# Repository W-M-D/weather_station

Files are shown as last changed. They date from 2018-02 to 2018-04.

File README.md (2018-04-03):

# weather_station

The ultimate in nrf52832 based APRS weather stations! 

Just a quick update after finding that you can buy a weather station replacement kit for ~$70 that has a few radios that is already supported by rtl_433 i sat down and did some thinking. What could i do that would be more universal. Like the ultimate Ham hacking kit. After much debate with myself. I have decided to make something much more generic.  But i also wanted to create something that was much more than a simple dev board. I'm keeping the universality down to one radio besides the Bluetooth one. But i am going to add a raspberry pi header for reasons. My goal is to make a device that, with your ham radio, you can create anything you desire within the limits of the community and APRS.

Another update i'm still going to make a version of the board with out the raspberry pi HAT. I'm going to elimiate most of the hardware since i'm planning on reading from external sensors. I'm planning on breaking out the nrf52832 to pin headers to connect the hardware. This will still run off 4 18650s and will still have the solar MPPT circuit.

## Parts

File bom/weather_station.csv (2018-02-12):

Id | Designator | Package | Quantity | Designation | Supplier and ref
1 | M1 | WireConnection_2.00mmDrill | 1 | ANEOMETER |  |  | 0
2 | C9 | C_0402 | 1 | 100pF | 399-1022-1-ND |  | 0
3 | BT1,BT2,BT3,BT4 | Keystone_1042_1x18650 | 4 | 18650Cell | 36-1042P-ND | $2.47 | 9.88 | 9.88
4 | C1,C2,C20 | C_1206 | 3 | 10uF | 490-5525-1-ND | 0.28 | 0.84 | 10.72
5 | C3 | C_0402 | 1 | 4.7uF | 490-5915-1-ND | $0.16 | 0.16 | 10.88
6 | C4,C10,C11,C21,C25 | C_0402 | 5 | 100nF | 587-1227-1-ND | $0.10 | 0.5 | 11.38
7 | C5,C7,C16,C18 | C_0402 | 4 | F_cap | N/A |  | 0 | 11.38
8 | C6,C17 | C_0402 | 2 | Diff_Cap | N/A |  | 0 | 11.38
9 | C8,C23 | C_0402 | 2 | 1uF | 587-1251-1-ND | $0.10 | 0.2 | 11.58
10 | C14,C15 | C_0402 | 2 | 12pF | 490-6197-1-ND | $0.10 | 0.2 | 11.78
11 | D2 | LED_RGB_PLCC-6 | 1 | LTRB GFSF | 475-2899-1-ND | 1.08 | 1.08 | 12.86
12 | DRA1 | DRA818U | 1 | DRA818U | DRA818V | 9.44 | 9.44 | 22.3
13 | L3 | C_0402 | 1 | 3.3nH | 712-1416-1-ND | $0.10 | 0.1 | 22.4
14 | L4 | C_0402_NoSilk | 1 | tuning_inductor |  |  | 0 | 22.4
15 | MK1,MK2,MK3,MK4 | MountingHole_3.5mm_Pad | 4 | Mounting_Hole | N/A | 0 | 0 | 22.4
16 | U1 | SO-8C | 1 | LM1117IMP-3.3 | LM1117IMP-3.3 | 1.14 | 1.14 | 23.54
17 | U2 | TSSOP-16_4.4x5mm_Pitch0.65mm | 1 | ADS1120-PW | 296-39550-5-ND | 7.92 | 7.92 | 31.46
18 | U3 | UQFN-48-1EP_6x6mm_Pitch0.4mm | 1 | nRF52832 | 1490-1055-1-ND | 5.59 | 5.59 | 37.05
19 | Y1 | Crystal_SMD_3225-4pin_3.2x2.5mm | 1 | FL3200037 | FL3200037CT-ND | $0.69 | 0.69 | 37.74
20 | C22 | FV1206-1 | 1 | EMI_Filter_C | LFCN 180+ | $0.01 | 0.01 | 37.75
21 | JP1 | Pin_Header_Straight_1x02_Pitch2.54mm | 1 | Jumper | N/A |  | 0 | 37.75
22 | Q1 | SOT-23 | 1 | Q_NMOS_DGS | SSM3K329RLFCT-ND | 0.54 | 0.54 | 38.29
23 | C24 | C_0402 | 1 | 10nF | 490-1313-1-ND | $0.10 | 0.1 | 38.39
24 | C26,C29,C30 | C_0402 | 3 | C_Small | N/A |  | 0 | 38.39
25 | U5 | LGA-8_3x5mm_Pitch1.25mm | 1 | MPL115A1 | MPL115A1-ND | 5.85 | 5.85 | 44.24
26 | MK5,MK6,MK7,MK8 | Measurement_Point_Square-SMD-Pad_Big | 4 | Mounting_Hole_PAD |  |  | 0 | 44.24
27 | C12,C13 | C_0603 | 2 | tuning_cap |  |  | 0 | 44.24
28 | R1,R6,R10,R13 | R_0603 | 4 | 10MΩ | 311-10MGRCT-ND | 0.1 | 0.4 | 44.64
29 | R4,R5,R11,R12 | R_0603 | 4 | 510Ω | RHM510DCT-ND | $0.10 | 0.4 | 45.04
30 | R7,R8,R9 | R_0603 | 3 | 255Ω | RHM510DCT-ND | $1.10 | 3.3 | 48.34
31 | R16,R21,R30,R31,R32 | R_0603 | 5 | 100kΩ | RR08P100KDCT-ND | $0.11 | 0.55 | 48.89
32 | R17 | R_0603 | 1 | 3.3kΩ | RHM3.3KDCT-ND | 0.1 | 0.1 | 48.99
33 | R18 | R_0603 | 1 | 1.8KΩ | RR08P1.8KDCT-ND | $0.11 | 0.11 | 49.1
34 | U6 | QFN-24-1EP_3x3mm_Pitch0.4mm | 1 | LIS3MDLTR | 497-13892-1-ND | 1.67 | 1.67 | 50.77
35 | J3,J4 | SMA_SMD_Jack_Straight | 1 | Conn_Coaxial | J10154CT-ND | 5.38 | 10.76 | 61.53
36 | R2,R3 | R_0603 | 2 | 1.8kΩ | RR08P1.8KDCT-ND | 0.11 | 0.22 | 61.75
37 | J2 | Pin_Header_Straight_2x10_Pitch2.54mm | 1 | Conn_02x10_Odd_Even |  |  | 0 | 61.75
38 | Y2 | Crystal_SMD_EuroQuartz_EQ161-2pin_3.2x1.5mm | 1 | 32.786khz | 1253-1335-1-ND | 0.66 | 0.66 | 62.41
39 | AE1 | SMA | 1 | ant |  |  | 0 | 62.41
40 | C27,C28,C32,C34,C37,C39 | C_0805 | 6 | 1.0uF | 311-1365-1-ND | 0.11 | 0.66 | 63.07
41 | C31,C33,C38,C41,C42 | C_0805 | 5 | 0.1uF | 399-1170-1-ND | 0.1 | 0.5 | 63.57
42 | C35,C43 | CP_Elec_6.3x7.7 | 2 | 100uF | 493-2105-1-ND | 0.33 | 0.66 | 64.23
43 | C36,C40 | CP_Elec_6.3x7.7 | 2 | 47uF | 493-2176-1-ND | 0.35 | 0.7 | 64.93
44 | D3 | TO-252-2_Rectifier | 1 | MBRD10100CT | 1655-1464-1-ND | 0.45 | 0.45 | 65.38
45 | D4 | D_SOD-523 | 1 | D_Schottky | BZT585B5V1TQ-7DICT-ND | 0.29 | 0.29 | 65.67
46 | J6 | Pin_Header_Straight_1x02_Pitch2.54mm | 1 | SOLAR | 1597-1414-ND | 12.19 | 12.19 | 77.86
47 | L5 | Inductor_Wurth_HCI-1890 | 1 | 3.3uH | 732-2165-1-ND | 2.01 | 2.01 | 79.87
48 | Q2,Q3,Q4,Q5 | TDSON-8-1 | 4 | FDMS8050 | FDMS8050ET30CT-ND | 3.73 | 14.92 | 94.79
49 | R27,R28 | R_2512 | 2 | 0.010Ω | 311-0.1ARCT-ND | 0.57 | 1.14 | 95.93
50 | U4 | QFN-16-1EP_3x3mm_Pitch0.5mm | 1 | BQ24650 | 296-27699-1-ND | 5.52 | 5.52 | 101.45
51 | C19 | C_0805 | 1 | - | N/A |  | 0 | 101.45
52 | D5,D6 | LED_0805 | 2 | LED | 160-1423-1-ND | 0.29 | 0.58 | 102.03
53 | R14 | R_0603 | 1 | 10kΩ | RR08P10.0KDCT-ND |  | 0 | 102.03
54 | R15,R25,R26 | R_0603 | 3 | 5.23kΩ | 311-5.23KHRCT-ND | 0.1 | 0.3 | 102.33
55 | R19 | R_0603 | 1 | 30.1kΩ | 311-30.1KHRCT-ND | 0.1 | 0.1 | 102.43
56 | R20,R29 | R_0603 | 2 | 499kΩ | 311-2372-1-ND | 0.24 | 0.48 | 102.91
57 | R22 | R_0603 | 1 | 36kΩ | 311-36KGRCT-ND | 0.1 | 0.1 | 103.01
58 | R23 | R_0603 | 1 | - | jmpr |  | 0 | 103.01
59 | R24 | R_0603 | 1 | 10Ω | P10.0ABCT-ND | 0.1 | 0.1 | 103.11
60 | TH1 | R_0805 | 1 | Thermistor_NTC | 490-2454-1-ND | 0.21 | 0.21 | 103.32
 |  | battery | 4 | BATTERY LITHIUM 3.7V 2.6AH | 1568-1488-ND | 5.95 | 23.8 | 127.12
 |  |  |  |  |  |  |  |  | Total | 139.81

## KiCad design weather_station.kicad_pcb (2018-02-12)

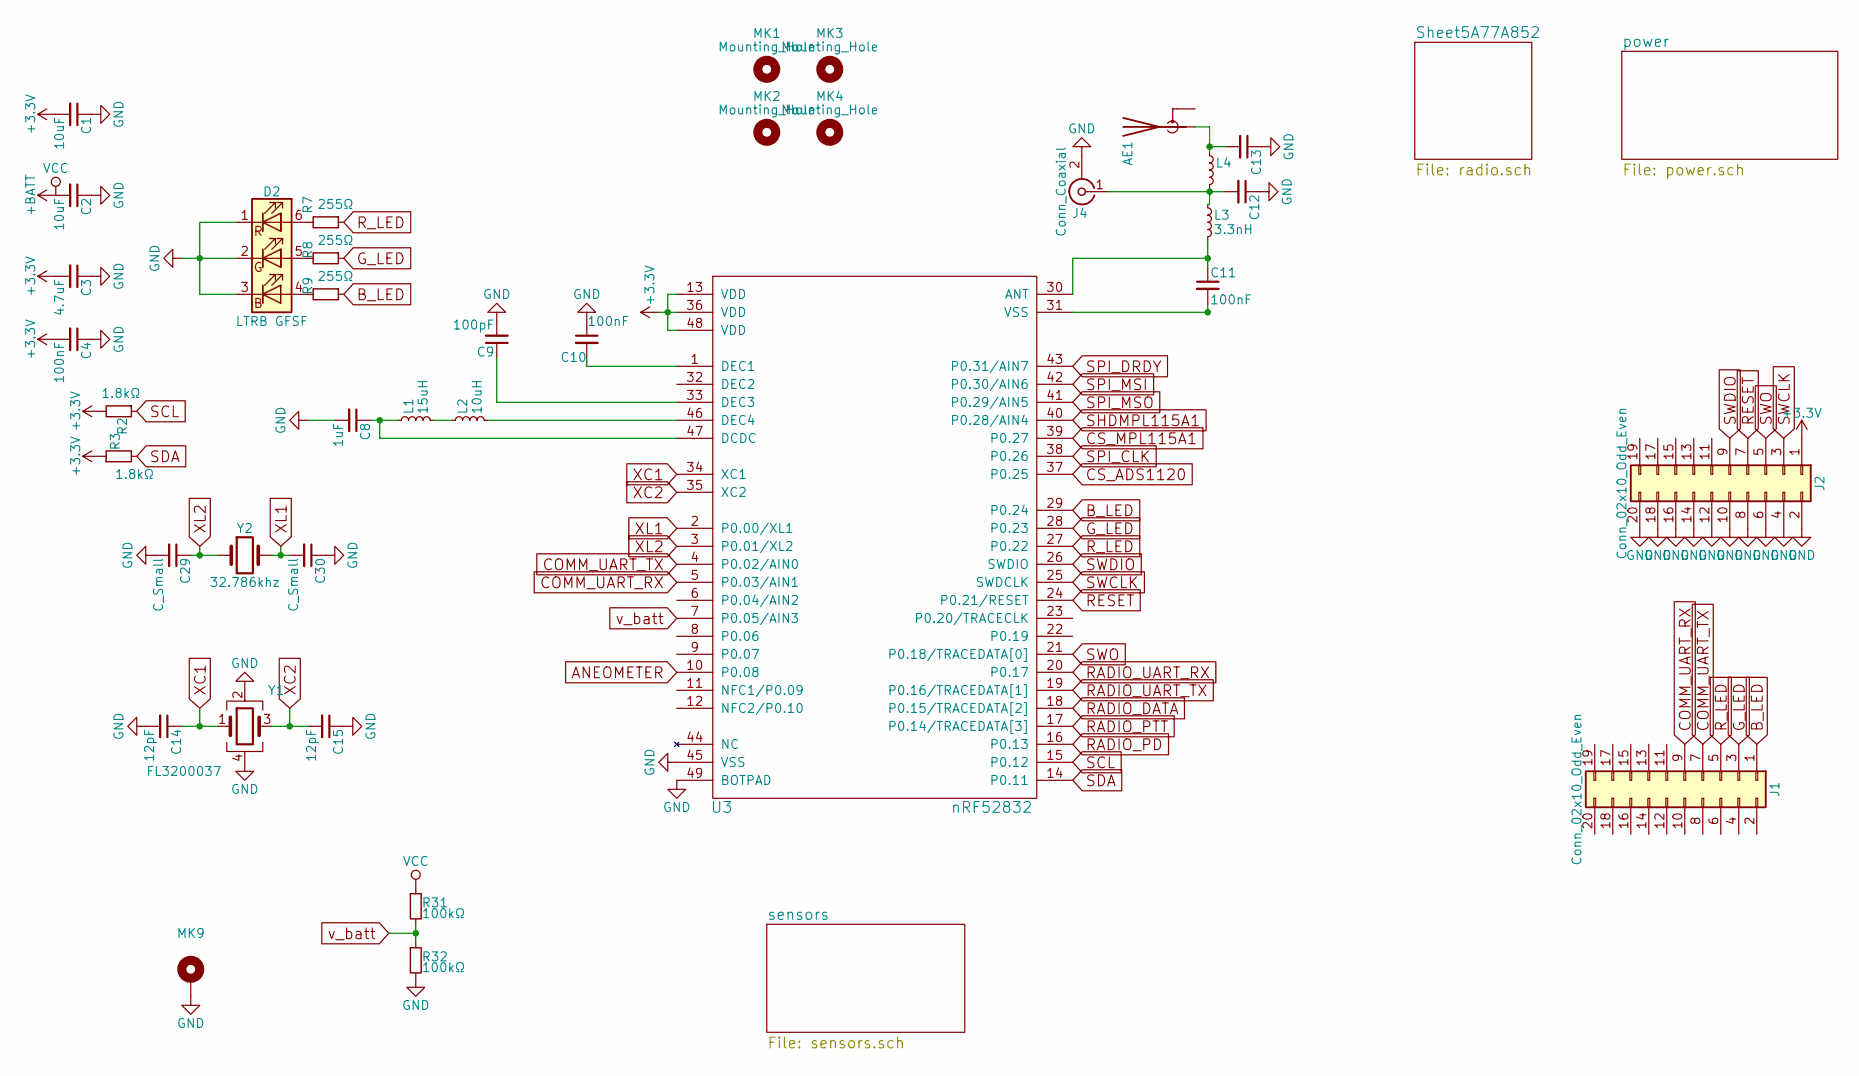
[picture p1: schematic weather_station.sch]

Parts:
AE1: ant; SMA
C1, C2: 10uF; C_1206
C3: 4.7uF; C_0402
C4, C10, C11: 100nF; C_0402
C8: 1uF; C_0402
C9: 100pF; C_0402
C12, C13: tuning_cap; C_0603
C14, C15: 12pF; C_0402
C29, C30: C_Small; C_0402
D2: LTRB GFSF; LED_RGB_PLCC-6
J1, J2: Conn_02x10_Odd_Even; Pin_Header_Straight_2x10_Pitch2.54mm
J4: Conn_Coaxial; SMA_SMD_Jack_Straight
L1: 15uH; C_0402
L2: 10uH; C_0603
L3: 3.3nH; C_0402
L4: tuning_inductor; C_0402_NoSilk
MK1, MK2, MK3, MK4: Mounting_Hole; MountingHole_3.5mm_Pad
MK9: via
R2, R3: 1.8kΩ; R_0603
R7, R8, R9: 255Ω; R_0603
R31, R32: 100kΩ; R_0603
U3: nRF52832; UQFN-48-1EP_6x6mm_Pitch0.4mm
Y1: FL3200037; Crystal_SMD_3225-4pin_3.2x2.5mm
Y2: 32.786khz; Crystal_SMD_EuroQuartz_EQ161-2pin_3.2x1.5mm

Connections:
+BATT: C2.2, R31.1; also elsewhere on the board
ANEOMETER: U3.10 (P0.08); also elsewhere on the board
B_LED: J1.1, R9.1, U3.29 (P0.24)
COMM_UART_RX: J1.9, U3.5 (P0.03/AIN1)
COMM_UART_TX: J1.7, U3.4 (P0.02/AIN0)
CS_ADS1120: U3.37 (P0.25); also elsewhere on the board
CS_MPL115A1: U3.39 (P0.27); also elsewhere on the board
G_LED: J1.3, R8.1, U3.28 (P0.23)
unnamed: AE1.1 (A), C13.2, L4.1
unnamed: C8.1, L1.1, U3.47 (DCDC)
unnamed: C9.1, U3.33 (DEC3)
unnamed: C10.2, U3.1 (DEC1)
unnamed: C11.1, L3.2, U3.30 (ANT)
unnamed: C11.2, U3.31 (VSS)
unnamed: C12.2, J4.1 (In), L3.1, L4.2
unnamed: D2.4 (BA), R9.2
unnamed: D2.5 (GA), R8.2
unnamed: D2.6 (RA), R7.2
unnamed: L1.2, L2.1
unnamed: L2.2, U3.46 (DEC4)
RADIO_DATA: U3.18 (P0.15/TRACEDATA[2]); also elsewhere on the board
RADIO_PD: U3.16 (P0.13); also elsewhere on the board
RADIO_PTT: U3.17 (P0.14/TRACEDATA[3]); also elsewhere on the board
RADIO_UART_RX: U3.20 (P0.17); also elsewhere on the board
RADIO_UART_TX: U3.19 (P0.16/TRACEDATA[1]); also elsewhere on the board
RESET: J2.7, U3.24 (P0.21/RESET)
R_LED: J1.5, R7.1, U3.27 (P0.22)
SCL: R2.1, U3.15 (P0.12); also elsewhere on the board
SDA: R3.2, U3.14 (P0.11); also elsewhere on the board
SHDMPL115A1: U3.40 (P0.28/AIN4); also elsewhere on the board
SPI_CLK: U3.38 (P0.26); also elsewhere on the board
SPI_DRDY: U3.43 (P0.31/AIN7); also elsewhere on the board
SPI_MSI: U3.42 (P0.30/AIN6); also elsewhere on the board
SPI_MSO: U3.41 (P0.29/AIN5); also elsewhere on the board
SWCLK: J2.3, U3.25 (SWDCLK)
SWDIO: J2.9, U3.26 (SWDIO)
SWO: J2.5, U3.21 (P0.18/TRACEDATA[0])
XC1: C14.1, U3.34 (XC1), Y1.1
XC2: C15.2, U3.35 (XC2), Y1.3
XL1: C30.2, U3.2 (P0.00/XL1), Y2.2
XL2: C29.1, U3.3 (P0.01/XL2), Y2.1
v_batt: R31.2, R32.1, U3.7 (P0.05/AIN3)

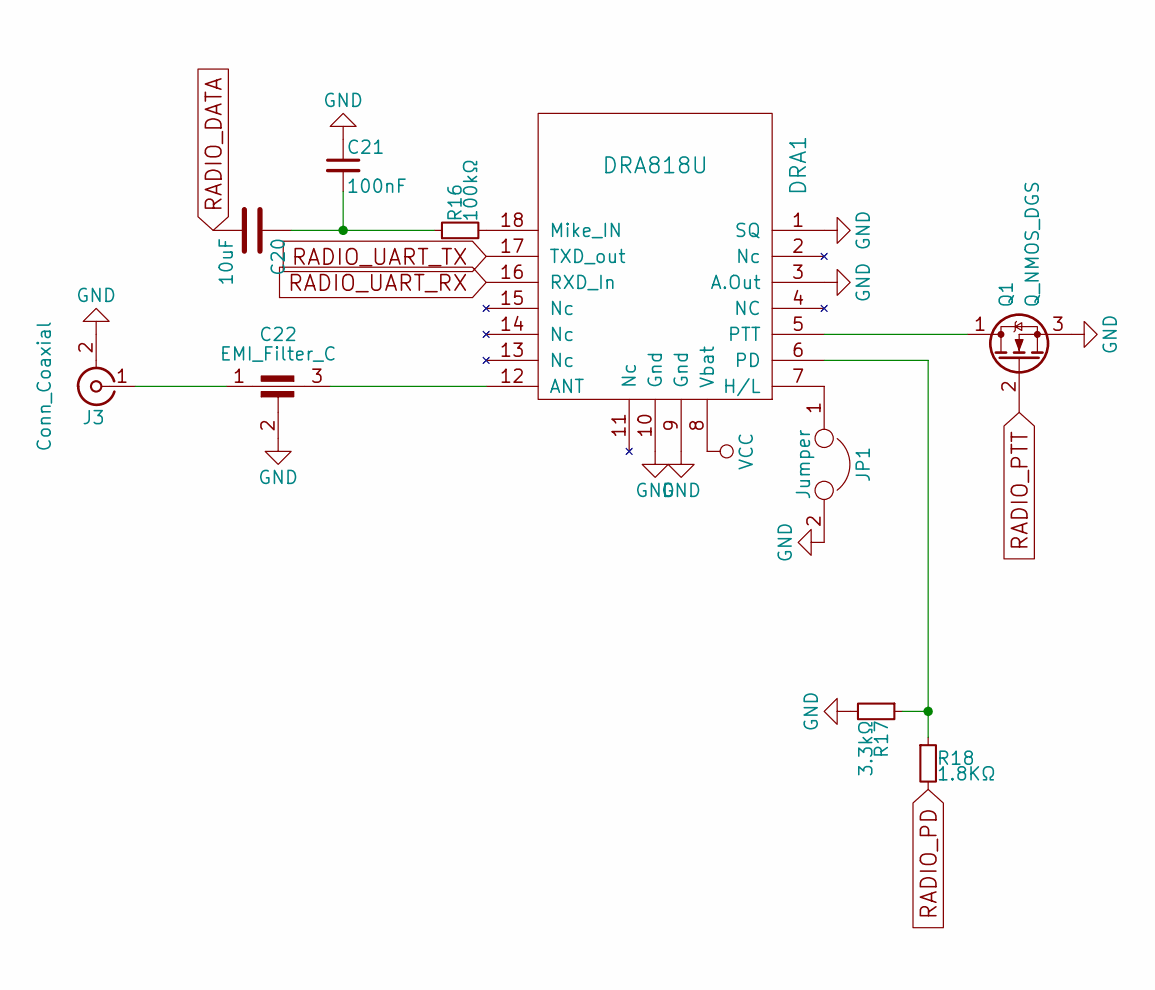
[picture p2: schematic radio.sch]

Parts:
C20: 10uF; C_1206
C21: 100nF; C_0402
C22: EMI_Filter_C; FV1206-1
DRA1: DRA818U
J3: Conn_Coaxial; SMA_SMD_Jack_Straight
JP1: Jumper; Pin_Header_Straight_1x02_Pitch2.54mm
Q1: Q_NMOS_DGS; SOT-23
R16: 100kΩ; R_0603
R17: 3.3kΩ; R_0603
R18: 1.8KΩ; R_0603

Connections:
+BATT: DRA1.8 (Vbat); also elsewhere on the board
unnamed: C20.1, C21.2, R16.1
unnamed: C22.1, J3.1 (In)
unnamed: C22.3, DRA1.12 (ANT)
unnamed: DRA1.5 (PTT), Q1.1 (D)
unnamed: DRA1.6 (PD), R17.1, R18.1
unnamed: DRA1.7 (H/L), JP1.1
unnamed: DRA1.18 (Mike_IN), R16.2
RADIO_DATA: C20.2; also elsewhere on the board
RADIO_PD: R18.2; also elsewhere on the board
RADIO_PTT: Q1.2 (G); also elsewhere on the board
RADIO_UART_RX: DRA1.16 (RXD_In); also elsewhere on the board
RADIO_UART_TX: DRA1.17 (TXD_out); also elsewhere on the board

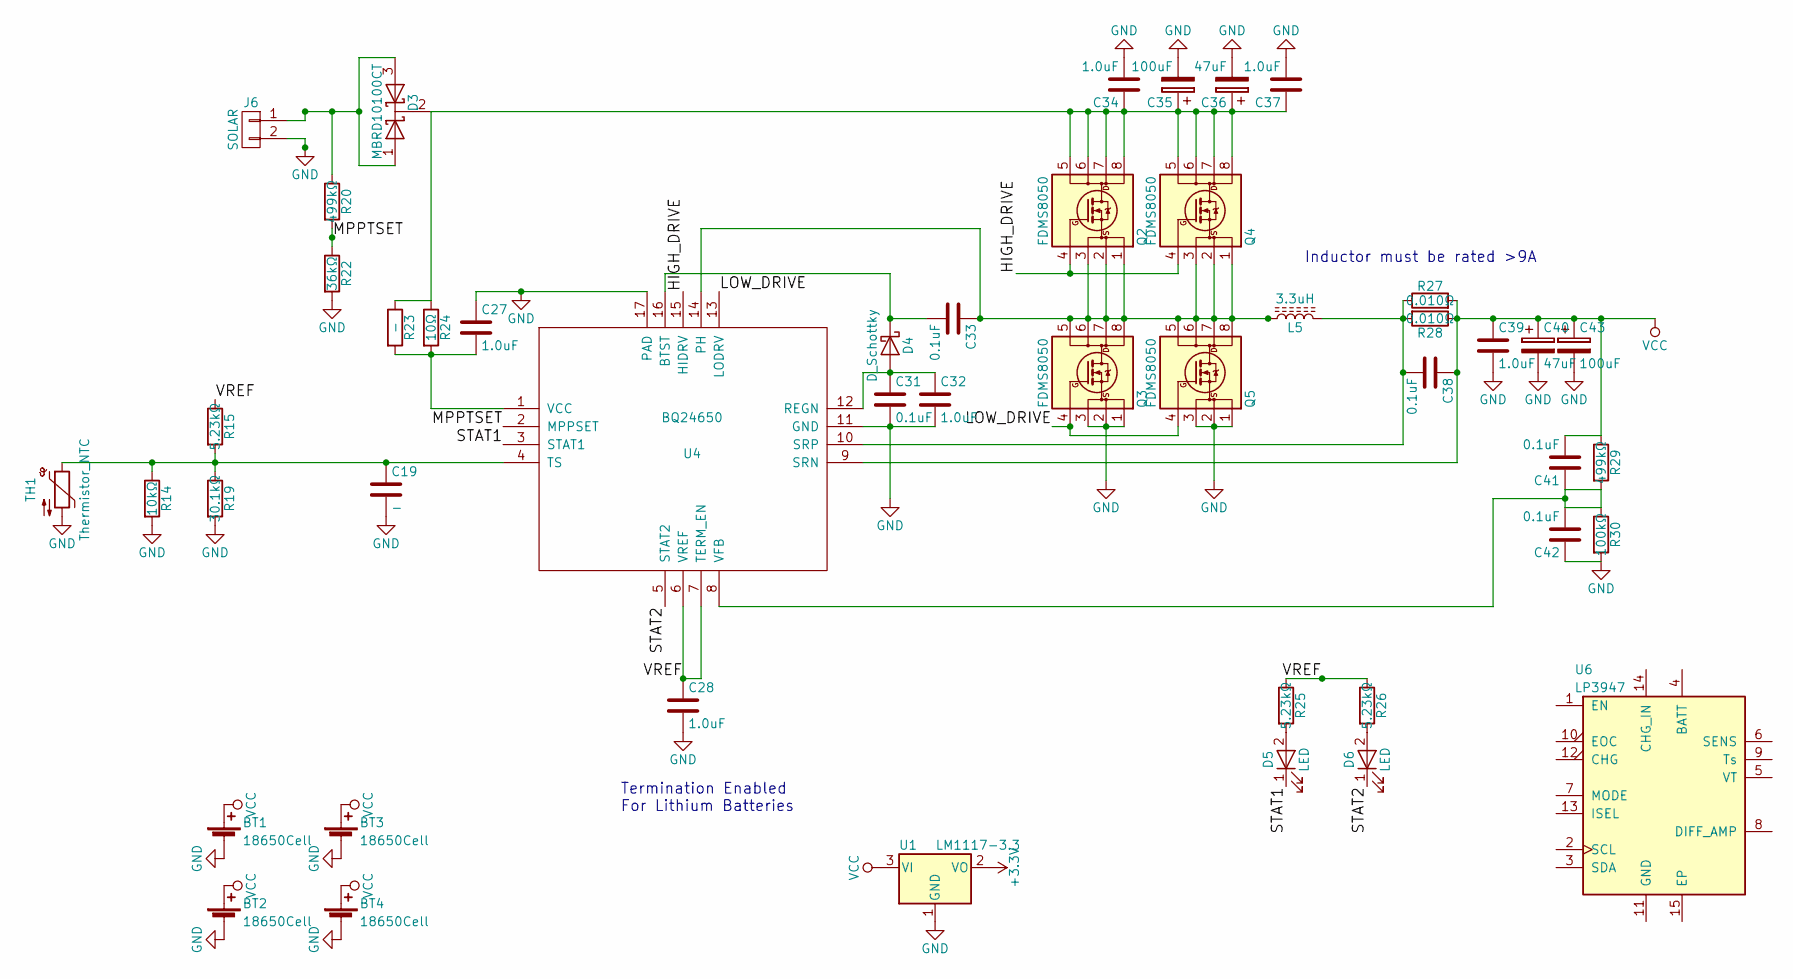
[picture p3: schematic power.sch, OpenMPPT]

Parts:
BT1, BT2, BT3, BT4: 18650Cell; Keystone_1042_1x18650
C19: -; C_0805
C27, C28, C32, C34, C37, C39: 1.0uF; C_0805
C31, C33, C38, C41, C42: 0.1uF; C_0805
C35, C43: 100uF; CP_Elec_6.3x7.7
C36, C40: 47uF; CP_Elec_6.3x7.7
D3: MBRD10100CT; TO-252-2_Rectifier
D4: D_Schottky; D_SOD-523
D5, D6: LED; LED_0805
J6: SOLAR; Pin_Header_Straight_1x02_Pitch2.54mm
L5: 3.3uH; Inductor_Wurth_HCI-1890
Q2, Q3, Q4, Q5: FDMS8050; TDSON-8-1
R14: 10kΩ; R_0603
R15, R25, R26: 5.23kΩ; R_0603
R19: 30.1kΩ; R_0603
R20, R29: 499kΩ; R_0603
R22: 36kΩ; R_0603
R23: -; R_0603
R24: 10Ω; R_0603
R27, R28: 0.010Ω; R_2512
R30: 100kΩ; R_0603
TH1: Thermistor_NTC; R_0805
U1: LM1117-3.3; SOT-223-3Lead_TabPin2
U4: BQ24650; QFN-16-1EP_3x3mm_Pitch0.5mm
U6: LP3947; WSON-14_1EP_4.0x4.0mm_Pitch0.5mm

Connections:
+BATT: BT1.1 (+), BT2.1 (+), BT3.1 (+), BT4.1 (+), C38.1, C39.1, C40.1, C41.2, C43.1, R27.2, R28.1, R29.1, U1.3 (VI), U1.8, U4.9 (SRN); also elsewhere on the board
/power/HIGH_DRIVE: Q2.4 (G), Q4.4 (G), U4.15 (HIDRV)
/power/LOW_DRIVE: Q3.4 (G), Q5.4 (G), U4.13 (LODRV)
/power/MPPTSET: R20.2, R22.1, U4.2 (MPPSET)
/power/STAT1: D5.1 (K), U4.3 (STAT1)
/power/STAT2: D6.1 (K), U4.5 (STAT2)
/power/VREF: C28.1, R15.1, R25.1, R26.1, U4.6 (VREF), U4.7 (TERM_EN)
MPU_INT: U6.12 (CHG)
unnamed: C19.1, R14.1, R15.2, R19.1, TH1.1, U4.4 (TS)
unnamed 28: U6.8 (DIFF_AMP); also elsewhere on the board
unnamed 29: U6.10 (EOC); also elsewhere on the board
unnamed: C27.2, R23.2, R24.2, U4.1 (VCC)
unnamed: C31.1, C32.1, D4.2 (A), U4.12 (REGN)
unnamed: C33.1, L5.1, Q2.1 (S), Q2.2 (S), Q2.3 (S), Q3.5 (D), Q3.6 (D), Q3.7 (D), Q3.8 (D), Q4.1 (S), Q4.2 (S), Q4.3 (S), Q5.5 (D), Q5.6 (D), Q5.7 (D), Q5.8 (D), U4.14 (PH)
unnamed: C33.2, D4.1 (K), U4.16 (BTST)
unnamed: C34.1, C35.1, C36.1, C37.1, D3.2 (K), Q2.5 (D), Q2.6 (D), Q2.7 (D), Q2.8 (D), Q4.5 (D), Q4.6 (D), Q4.7 (D), Q4.8 (D), R23.1, R24.1
unnamed: C38.2, L5.2, R27.1, R28.2, U4.10 (SRP)
unnamed: C41.1, C42.2, R29.2, R30.1, U4.8 (VFB)
unnamed: D3.1 (A), D3.3 (A), J6.1, R20.1
unnamed: D5.2 (A), R25.2
unnamed: D6.2 (A), R26.2
SCL: U6.23; also elsewhere on the board
SDA: U6.24; also elsewhere on the board

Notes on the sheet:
Termination Enabled For Lithium Batteries
Inductor must be rated >9A

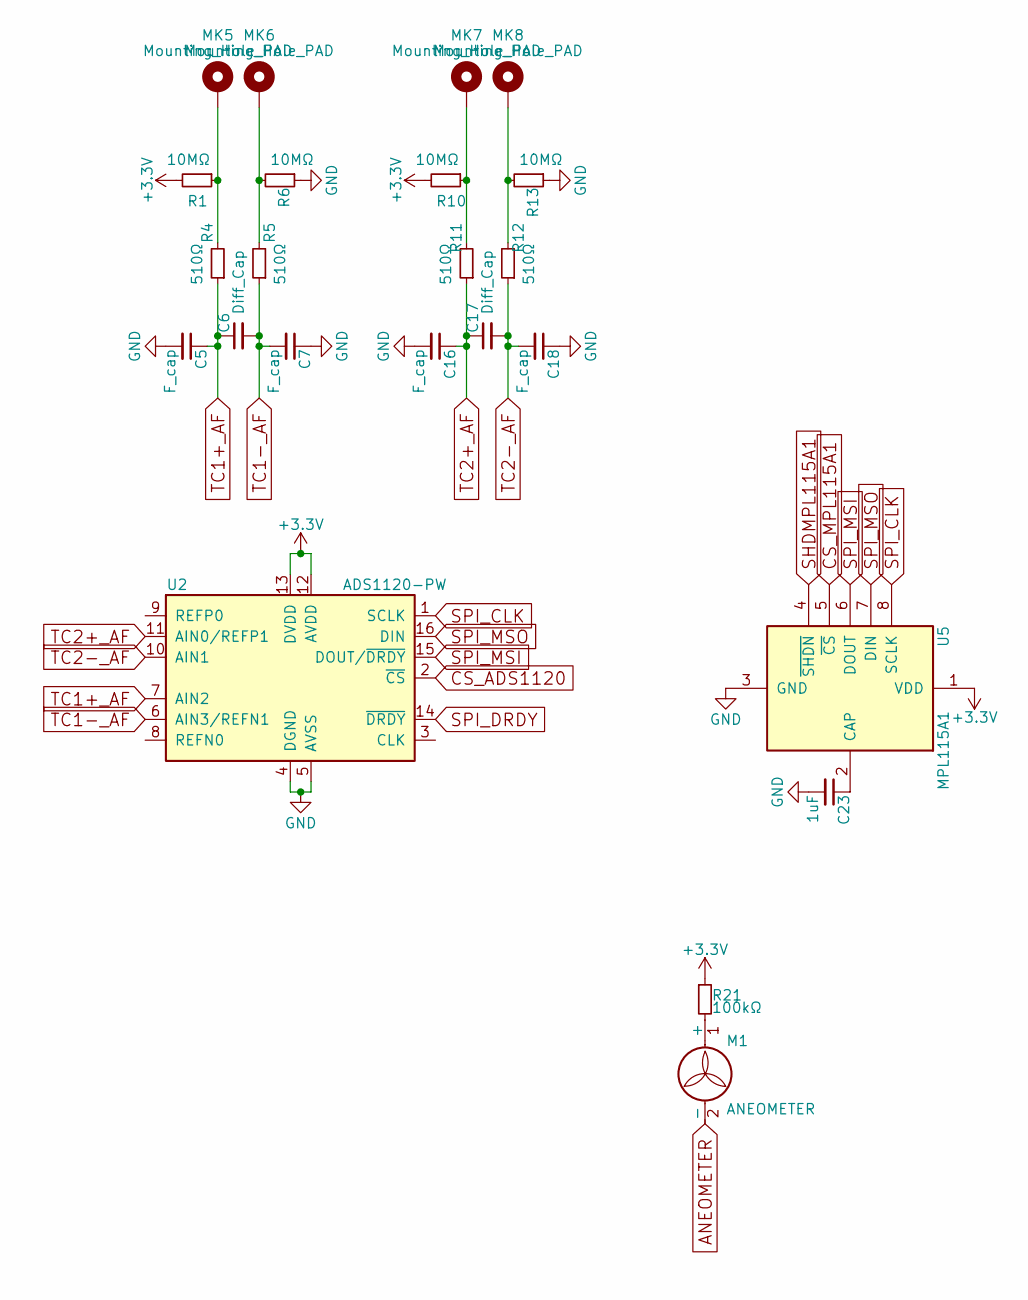
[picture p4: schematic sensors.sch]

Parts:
C5, C7, C16, C18: F_cap; C_0402
C6, C17: Diff_Cap; C_0402
C23: 1uF; C_0402
M1: ANEOMETER; WireConnection_2.00mmDrill
MK5, MK6, MK7, MK8: Mounting_Hole_PAD; Measurement_Point_Square-SMD-Pad_Big
R1, R6, R10, R13: 10MΩ; R_0603
R4, R5, R11, R12: 510Ω; R_0603
R21: 100kΩ; R_0603
U2: ADS1120-PW; TSSOP-16_4.4x5mm_Pitch0.65mm
U5: MPL115A1; LGA-8_3x5mm_Pitch1.25mm

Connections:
ANEOMETER: M1.2 (-); also elsewhere on the board
CS_ADS1120: U2.2 (~CS); also elsewhere on the board
CS_MPL115A1: U5.5 (~CS); also elsewhere on the board
unnamed: C23.1, U5.2 (CAP)
unnamed: M1.1 (+), R21.2
unnamed: MK5.1, R1.1, R4.2
unnamed: MK6.1, R5.2, R6.2
unnamed: MK7.1, R10.1, R11.2
unnamed: MK8.1, R12.2, R13.2
SHDMPL115A1: U5.4 (~SHDN); also elsewhere on the board
SPI_CLK: U2.1 (SCLK), U5.8 (SCLK); also elsewhere on the board
SPI_DRDY: U2.14 (~DRDY); also elsewhere on the board
SPI_MSI: U2.15 (DOUT/~DRDY), U5.6 (DOUT); also elsewhere on the board
SPI_MSO: U2.16 (DIN), U5.7 (DIN); also elsewhere on the board
TC1+_AF: C5.1, C6.1, R4.1, U2.7 (AIN2)
TC1-_AF: C6.2, C7.2, R5.1, U2.6 (AIN3/REFN1)
TC2+_AF: C16.1, C17.1, R11.1, U2.11 (AIN0/REFP1)
TC2-_AF: C17.2, C18.2, R12.1, U2.10 (AIN1)

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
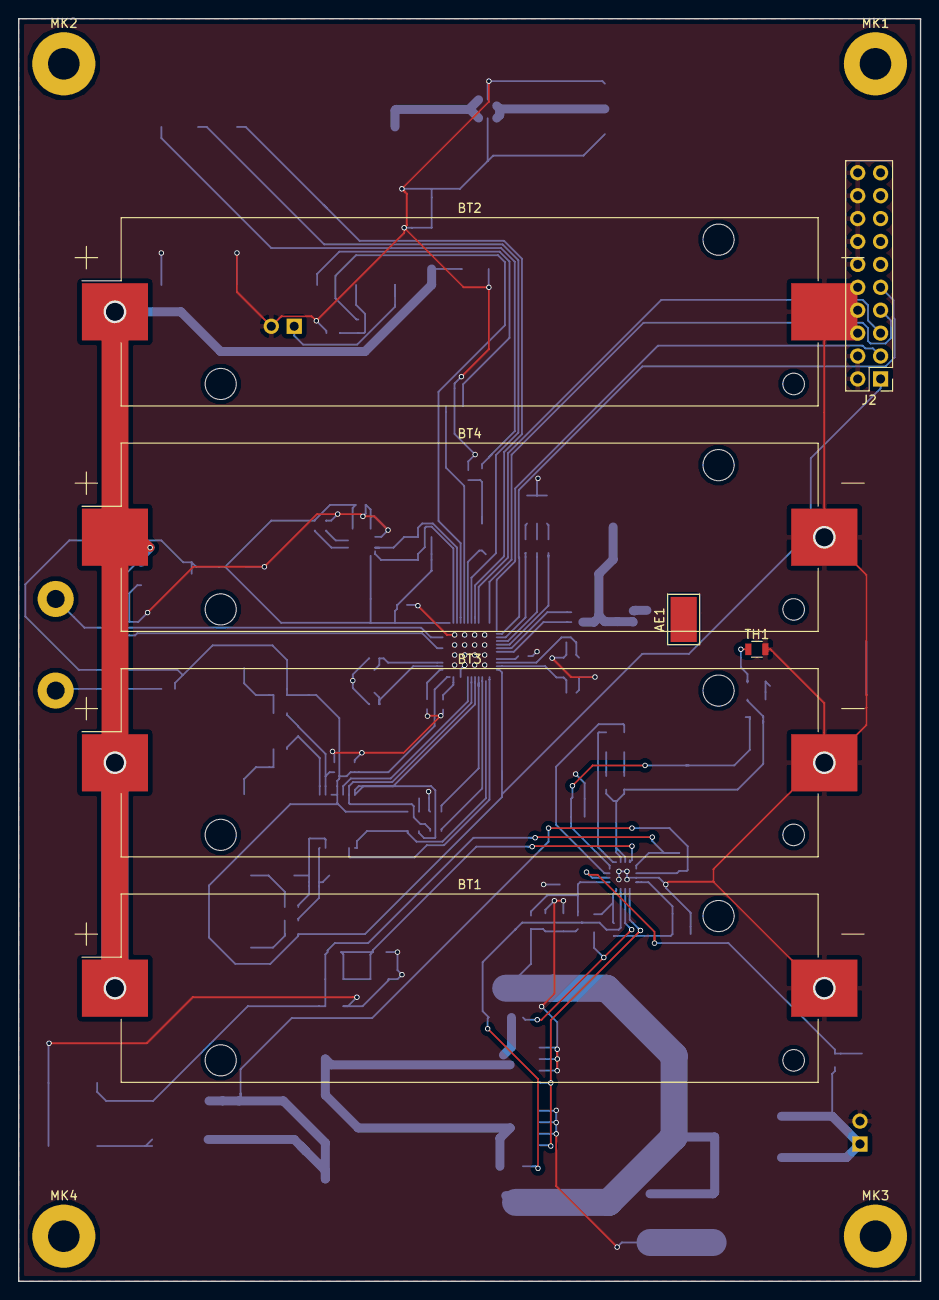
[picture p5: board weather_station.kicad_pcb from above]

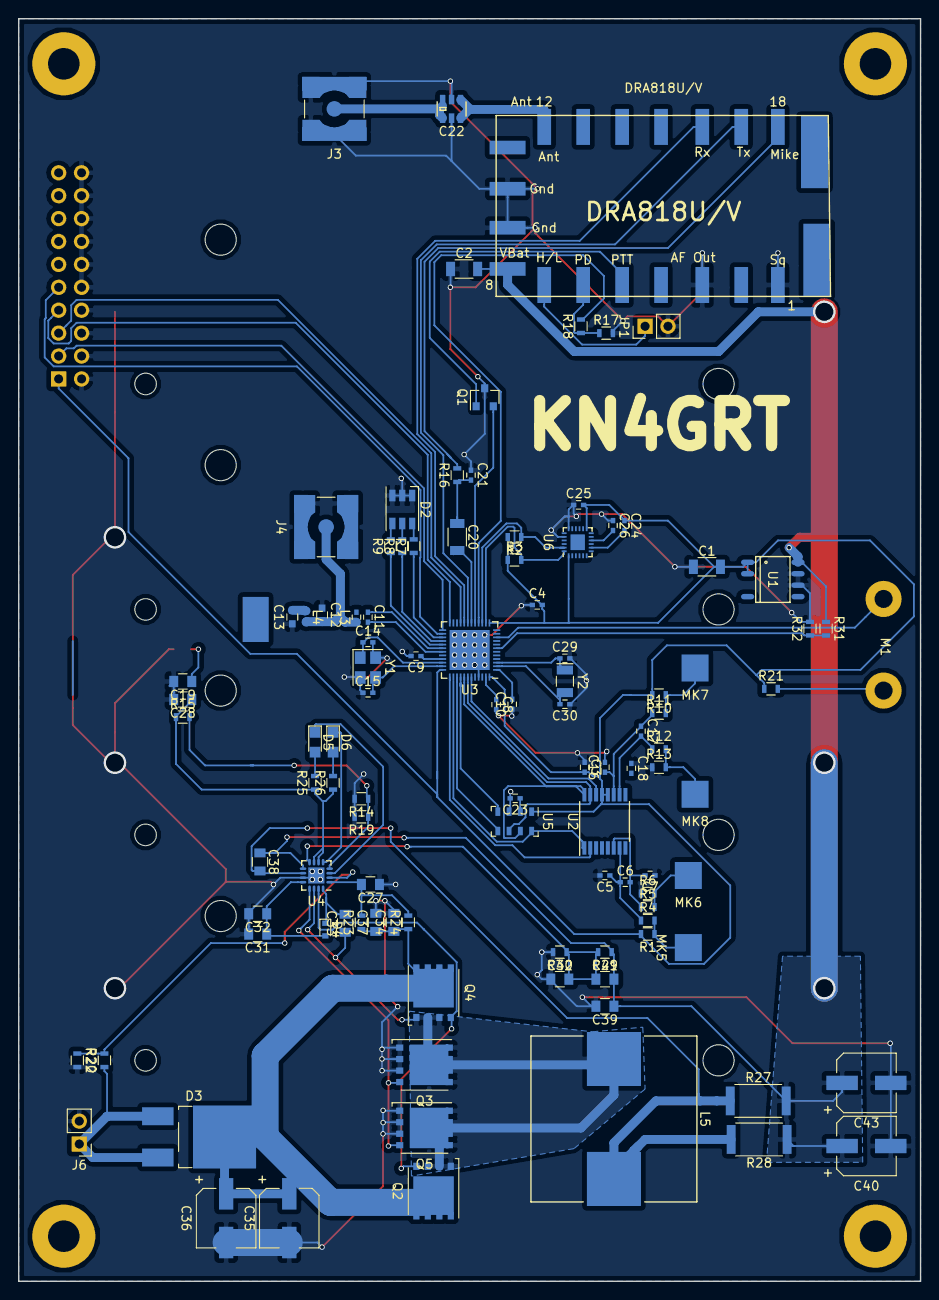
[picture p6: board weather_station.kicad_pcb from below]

Board: 2 copper layers, 100.0 x 140.0 mm, 117 parts (106 on the bottom side), 76 nets.

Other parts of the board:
C24: 10nF; C_0402
C25: 100nF; C_0402
C26: C_Small; C_0402

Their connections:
unnamed 28: C24.2; also elsewhere on the board
unnamed 29: C26.2; also elsewhere on the board

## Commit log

2018-02-04 init add
    [_saved_radio.sch, _saved_weather_station.sch, power.sch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]
2018-02-04 basing solar power supply off of openMPPT
    [_saved_weather_station.sch, power.sch, radio.sch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]
2018-02-04 well this is going to be easy to route...
    [weather_station.kicad_pcb]
2018-02-04 almost done
    [power.sch, radio.sch, sensors.sch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]
2018-02-04 well that wasn't centered
    [weather_station.kicad_pcb]
2018-02-04 might as well be able to monitor battery voltage from the nrf52832
    [power.sch, radio.sch, sensors.sch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]
2018-02-05 i think that's enough for now
    [power.sch, radio.sch, sensors.sch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]
2018-02-12 some cost savings
    [power.sch, radio.sch, sensors.sch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]
